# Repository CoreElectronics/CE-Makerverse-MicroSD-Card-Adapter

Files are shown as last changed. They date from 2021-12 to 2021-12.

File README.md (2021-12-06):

# Makerverse™ MicroSD Card Adapter



This is the repo for the Core Electronics [Makerverse™ MicroSD Card Adapter](https://core-electronics.com.au/catalog/product/view/sku/CE07926).

The PCB project requires KiCAD 5.99 or later to edit but the PDF schematic is in the Documents folder.

## License
This project is open source - please review the LICENSE.md file for further licensing information.

If you have any technical questions, or concerns about licensing, please contact technical support on the [Core Electronics forums](https://forum.core-electronics.com.au/).

*\"Makerverse\" and the Makerverse logo are trademarks of Core Electronics Pty Ltd.*

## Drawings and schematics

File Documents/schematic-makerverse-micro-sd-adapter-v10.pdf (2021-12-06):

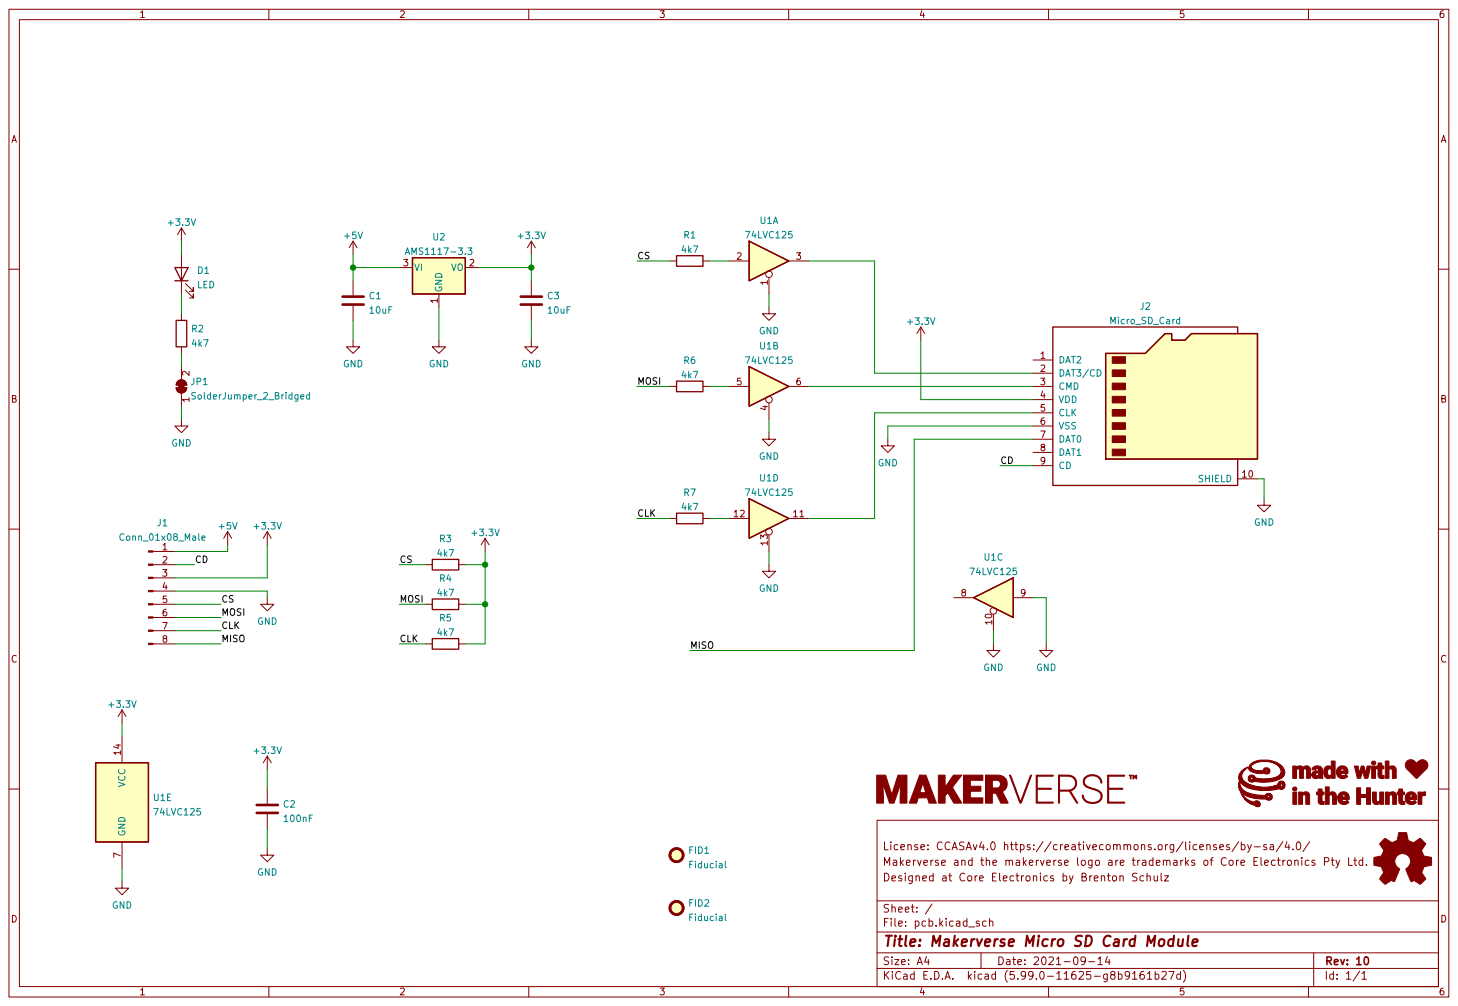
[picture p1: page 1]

License: CCASAv4.0 https://creativecommons.org/licenses/by-sa/4.0/ R5

Makerverse and the makerverse logo are trademarks of Core Electronics Pty Ltd.
File: pcb.kicad_sch Sheet: / Designed at Core Electronics by Brenton Schulz

Id: 1/1 Title: Makerverse Micro SD Card Module

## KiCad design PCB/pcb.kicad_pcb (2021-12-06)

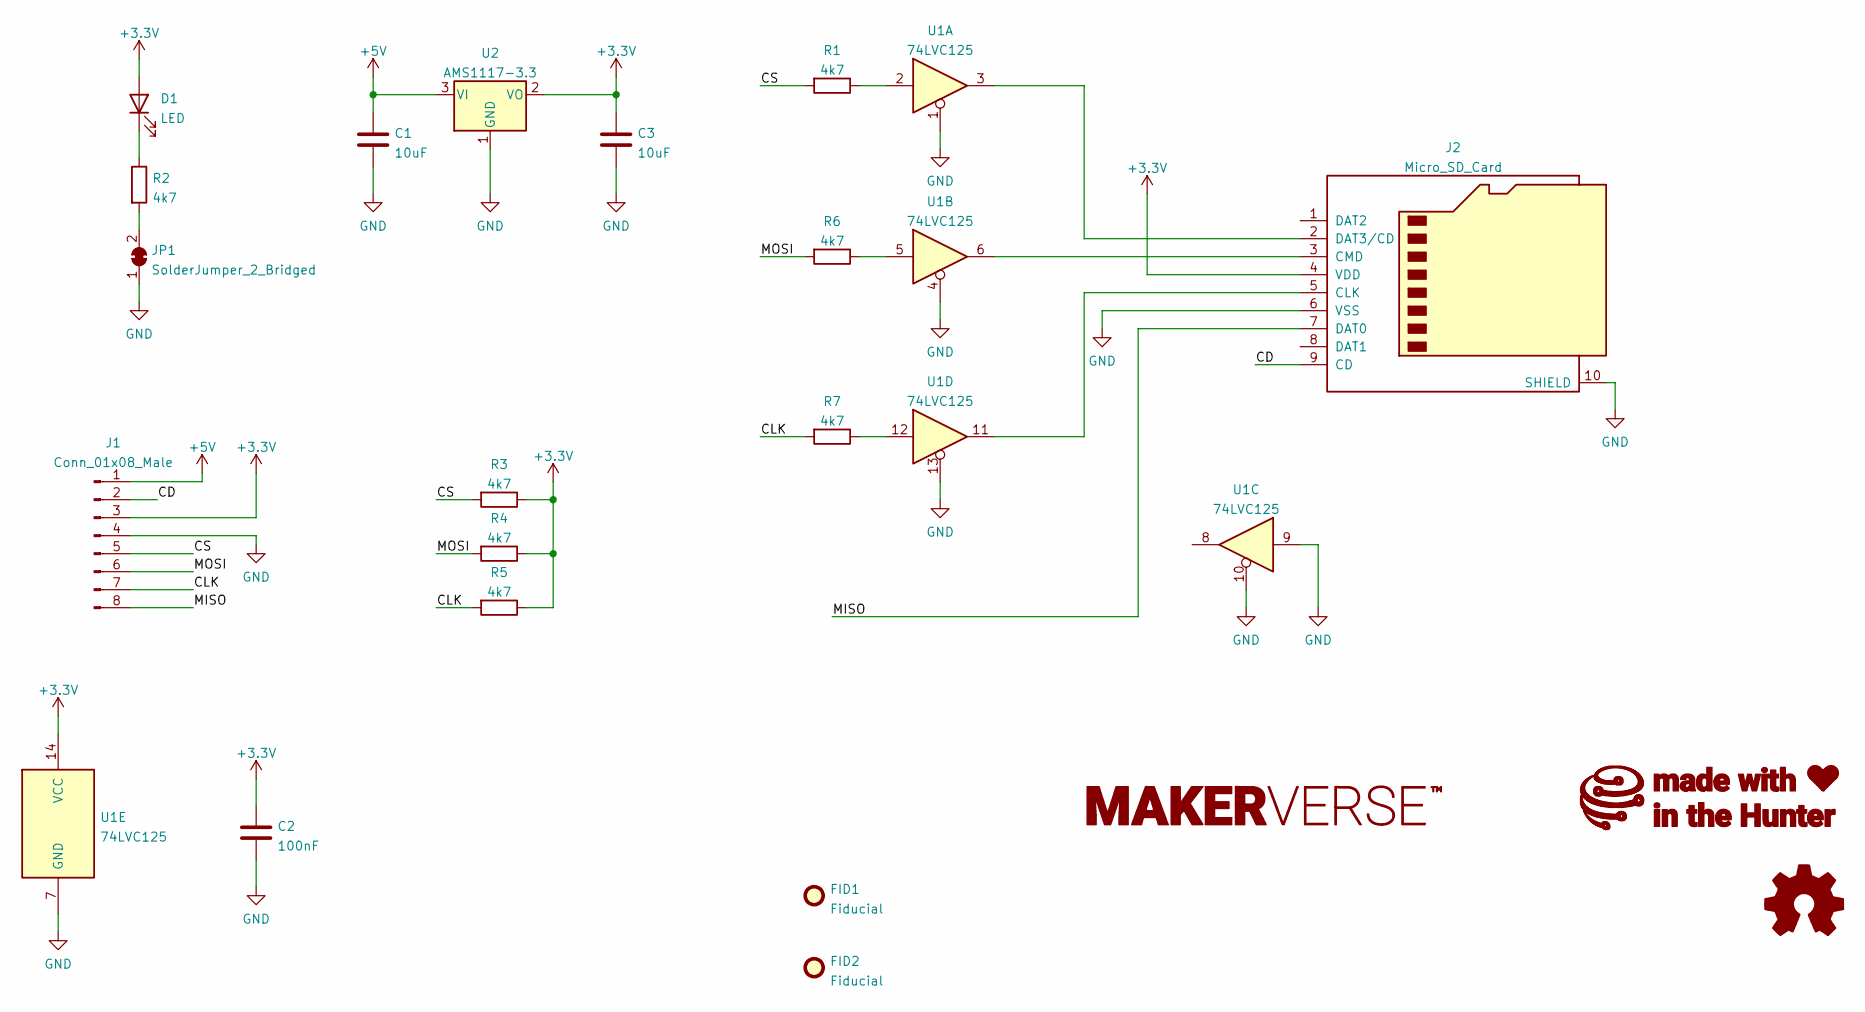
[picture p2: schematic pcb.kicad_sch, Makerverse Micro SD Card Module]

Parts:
C1, C3: 10uF; C_0603_1608Metric
C2: 100nF; C_0402_1005Metric
D1: LED; LED_0603_1608Metric
FID1, FID2: Fiducial; Fiducial_1mm_Mask2mm
J1: Conn_01x08_Male; PinHeader_1x08_P2.54mm_Vertical_SMD_Symmetric
J2: Micro_SD_Card; Micro-SD-9Pin
JP1: SolderJumper_2_Bridged; SolderJumper-2_P1.3mm_Bridged_RoundedPad1.0x1.5mm
R1, R2, R3, R4, R5, R6, R7: 4k7; R_0402_1005Metric
U1: 74LVC125; QFN50P250X300X100-15N-D
U2: AMS1117-3.3; SOT-89-3

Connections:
+3V3: C2.1, C3.1, D1.2 (A), J1.3, J2.4 (VDD), R3.1, R4.1, R5.1, U1.14 (VCC), U2.2 (VO)
+5V: C1.1, J1.1, U2.3 (VI)
/CD: J1.2, J2.9 (CD)
/CLK: J1.7, R5.2, R7.2
/CS: J1.5, R1.2, R3.2
/MISO: J1.8, J2.7 (DAT0)
/MOSI: J1.6, R4.2, R6.2
GND: C1.2, C2.2, C3.2, J1.4, J2.6 (VSS), J2.10 (SHIELD), JP1.1 (A), U1.1, U1.4, U1.7 (GND), U1.9, U1.10, U1.13, U2.1 (GND)
unnamed: D1.1 (K), R2.1
unnamed: J2.2 (DAT3/CD), U1.3
unnamed: J2.3 (CMD), U1.6
unnamed: J2.5 (CLK), U1.11
unnamed: JP1.2 (B), R2.2
unnamed: R1.1, U1.2
unnamed: R6.1, U1.5
unnamed: R7.1, U1.12

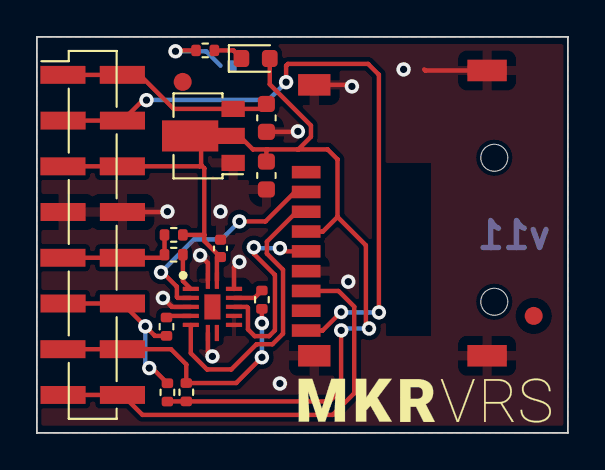
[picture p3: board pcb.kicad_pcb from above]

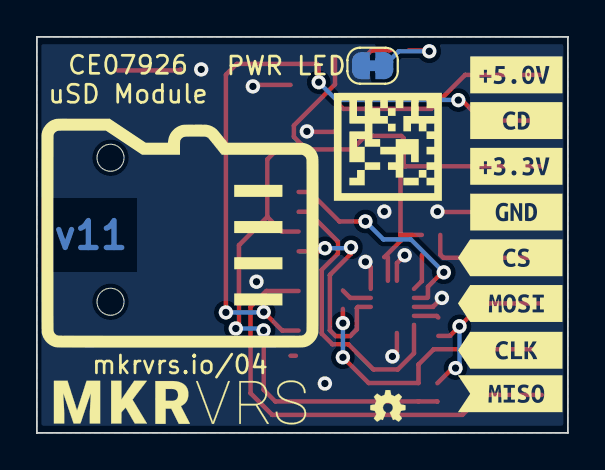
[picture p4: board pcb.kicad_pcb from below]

Board: 2 copper layers, 29.5 x 22.0 mm, 26 parts (9 on the bottom side), 16 nets.

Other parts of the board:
kibuzzard-6110B0BA: G***; kibuzzard-6110B0BA
kibuzzard-6110B0C2: G***; kibuzzard-6110B0C2
kibuzzard-6110B0C8: G***; kibuzzard-6110B0C8
kibuzzard-6110B0D8: G***; kibuzzard-6110B0D8
kibuzzard-6110B06E: G***; kibuzzard-6110B06E
kibuzzard-6110B07E: G***; kibuzzard-6110B07E
kibuzzard-6110B094: G***; kibuzzard-6110B094
kibuzzard-6111B463: G***; kibuzzard-6111B463
